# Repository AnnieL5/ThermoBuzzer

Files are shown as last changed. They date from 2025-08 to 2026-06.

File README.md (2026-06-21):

## ThermoBuzzer, a Thermosenser to Prevent Over Boiled Pots. 

### What it is
This device integrates a thermosensor, buzzer, and a button, and can make alarms when the temperature (the steam it detects) reaches a certain threshold. 

### Motivation / Inspiration / Problem

One Saturday afternoon my father left the stove, with the water heating up, for almost half an hour until the pot boiled dry and the fire alarm turned on, simply because he forgot the fact that the stove is still on. That moment inspired me to make a change - to build a device that could sense the temperature and alarm people that the burner is still active. 

### How to use it

1. Solder the electrical parts (see BOM) onto the PCB. Insert the PCB into the case and secure using m3 self-tapping screws

2. Insert the battery to start the machine. Slide in the lid and secure using a m3 self-tapping screw

3. Place it near the stoves. 

    Once the temperature continuously reaches 50 degrees (able to modify using a constant), ThermoBuzzer will beep continuously every five minutes until the button is clicked to ensure someone is there.

    Once the temperature reaches 70 degrees (able to modify using a constant), ThermoBuzzer will beep continuously right away until the button is clicked.

4. (Optional) To adjust the temperature threshold, take out the pcb from the case, modify amd reupload the program to the arduino pro mini.

### Code Example
Go checkout the example code in firmware/thermobuzzer.imo and upload it onto the arduino pro mini

For how to upload code onto arduino pro mini using arduino uno, check out 
https://www.instructables.com/How-to-Program-Arduino-Pro-Mini-Using-Arduino-UNO/

### Image of the entire cad / Finished product
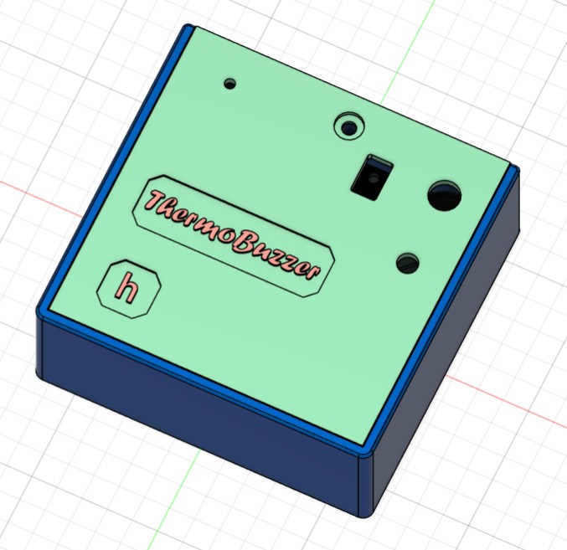
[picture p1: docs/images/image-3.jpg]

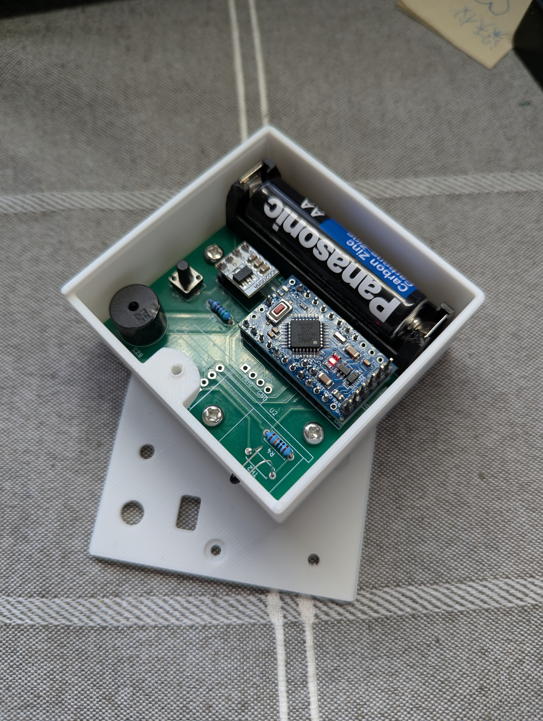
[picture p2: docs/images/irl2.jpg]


### Image of the entire cad (with lid) / Finished product
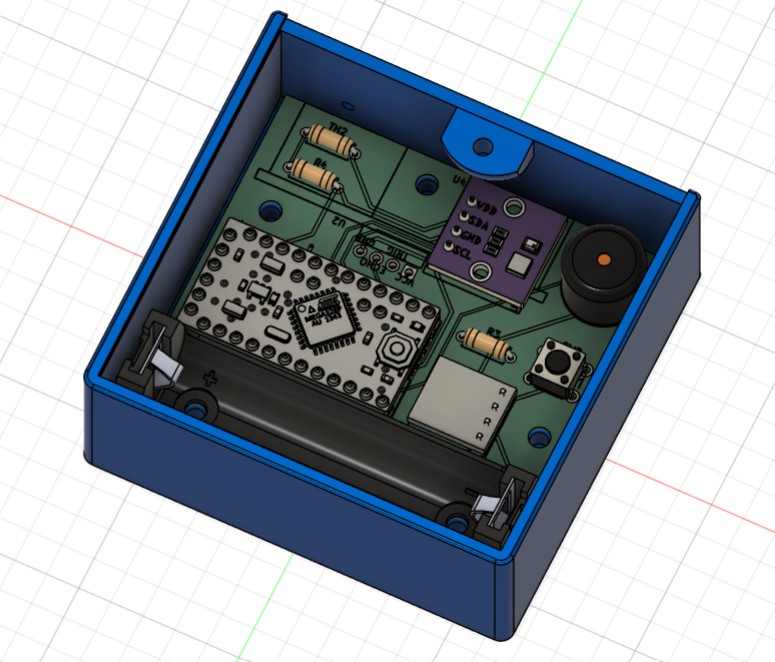
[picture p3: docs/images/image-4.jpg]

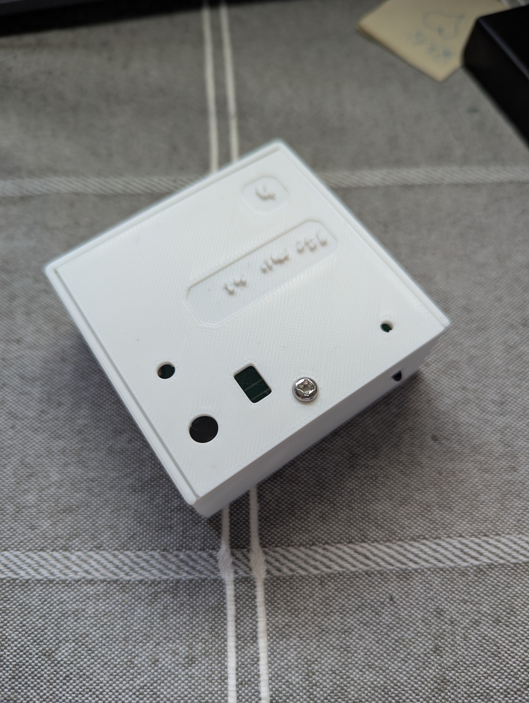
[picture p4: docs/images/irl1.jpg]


### Image of the final PCB
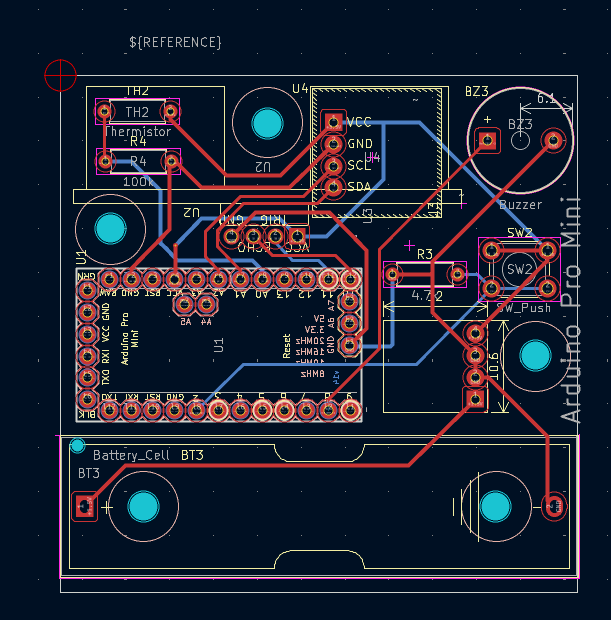
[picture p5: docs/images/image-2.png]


### Image of the wiring schematic
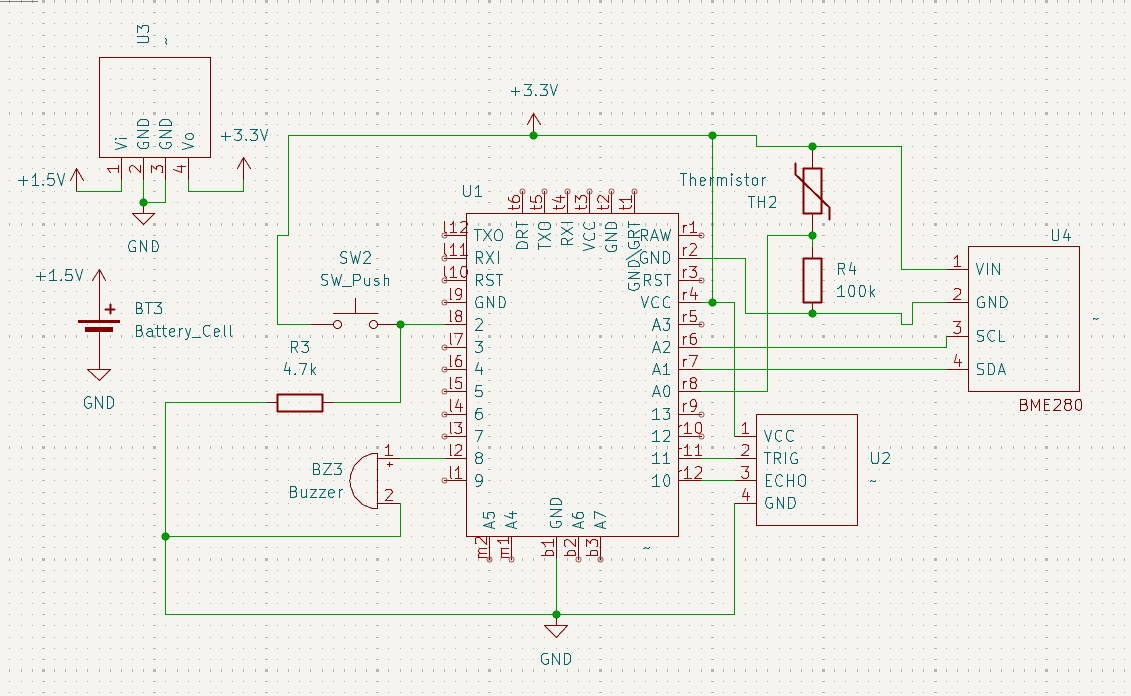
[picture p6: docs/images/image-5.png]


## Zine page

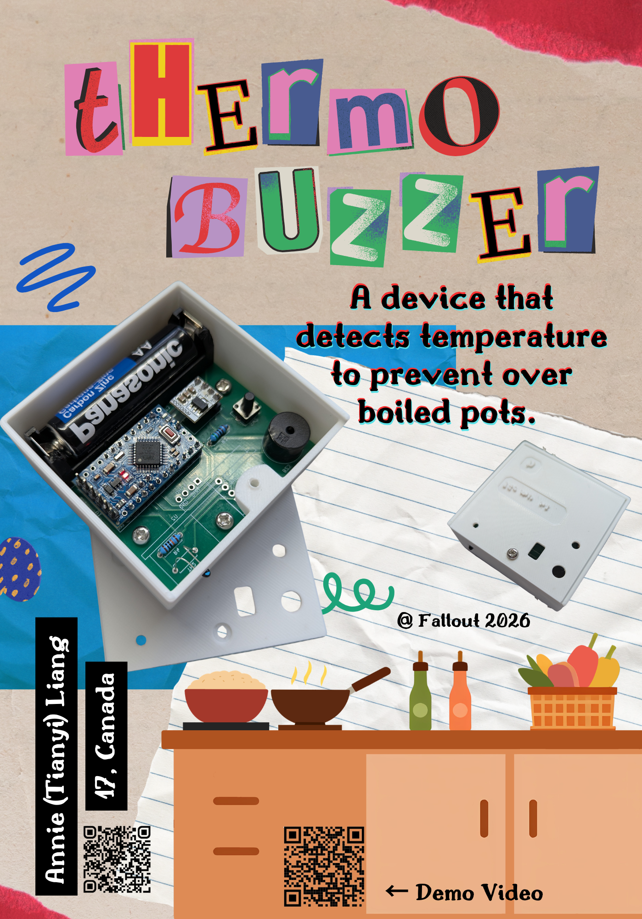
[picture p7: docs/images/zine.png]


## Demo Video

https://youtu.be/lv5Z6S4dAAs

## Product Design

### CAD dimensions
Side + top + base thickness: 2mm
supporting bar: r=4mm, h=4mm
Case height: 2mm base + 4mm supporting bar + 1.6mm board + 15.1mm battery height + 2mm flex + 2mm top

### Circuit Diagram 
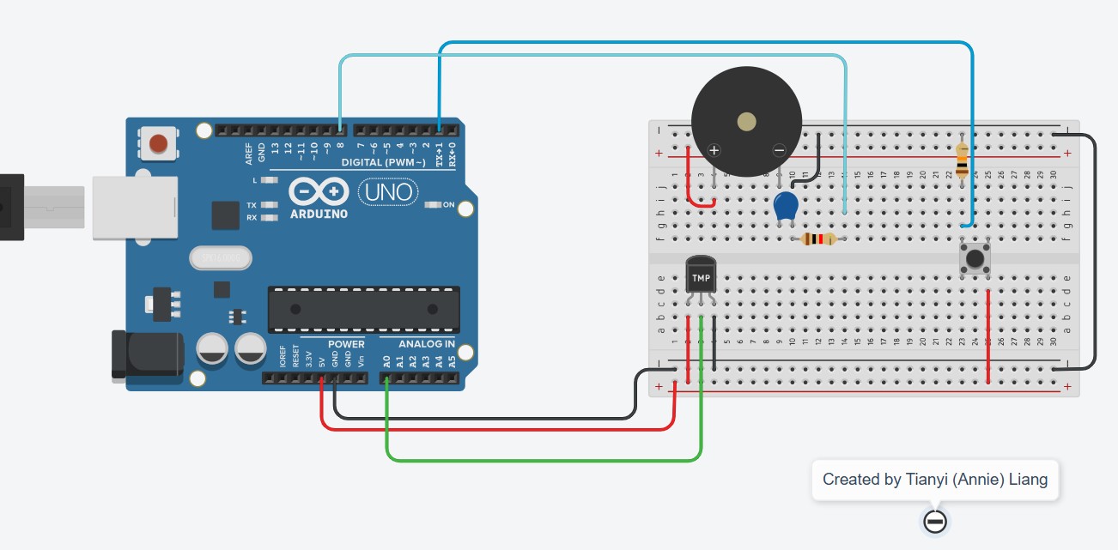
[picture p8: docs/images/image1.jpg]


### Sub-circuit Description
Diagrams from www.circuitbasics.com. 
#### Temperature sensor (NTC MF11) and Arduino

NTC MF11
The value of the resistor should be roughly equal to the resistance of the thermistor.
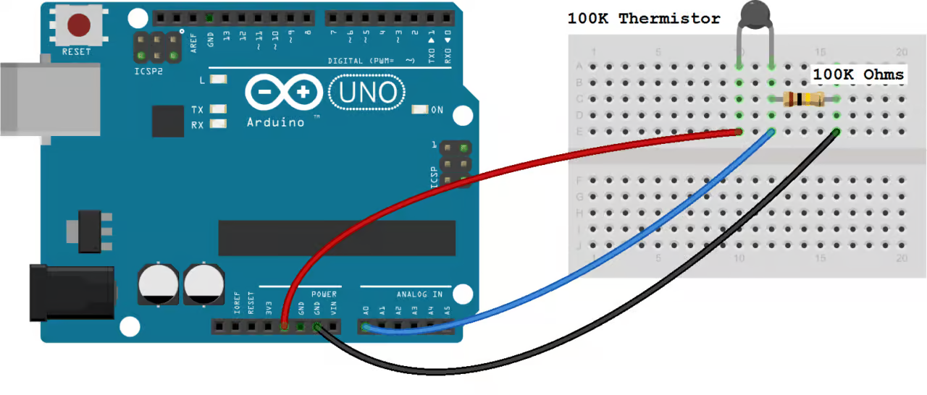
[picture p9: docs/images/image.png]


#### BME280
Reference links:

BME280
https://randomnerdtutorials.com/bme280-sensor-arduino-pressure-temperature-humidity/

https://docs.cirkitdesigner.com/component/3d8e6da8-841a-47a6-a1aa-0aa902c905e1/aht20bmp280

Code: https://randomnerdtutorials.com/bme280-sensor-arduino-pressure-temperature-humidity/

Arduino Library: adafruit bme280

It supports SPI or I2C communication

| BME280 |	Arduino |
|--|--|
|Vin | 	5V |
|GND |	GND |
|SCL |	A5 |
|SDA |	A4 |

| BME280 |	Arduino |
|--|--|
|SCK (SPI Clock)|	Pin 13|
|SDO (MISO)|	Pin 12|
|SDI (MOSI)|	Pin 11|
|CS (Chip Select)|	Pin 10|

#### Buzzer, Button and Arduino

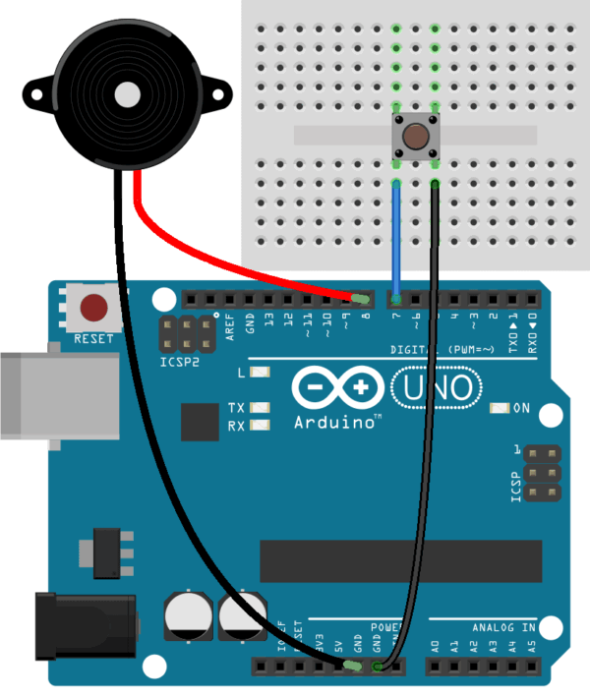
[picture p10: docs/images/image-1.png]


## Requirements (Need future work)
| Req # | Requirements |
|---|---|
| 1.1 | The thermosensor shall be able to measure the temperature accurately for further actions|
| 1.2 | The thermosensor shall be able to beep when the temperature reaches a certain threshold |
| 1.3 | The button should be able to stop the buzzer from beeping |
| 1.4 | The temperature threshold should be adjustable by the user |

## Bill of Materials (BOM)
| Product name | Product Description | Amount | Unit Price | Shipping Fee | Total Price | Link |
| --- | --- | --- | --- | --- | --- | --- |
| Arduino Pro Mini, | ÊATMEGA328P 3.3V 8MHz | 1 | $6.14 | | $6.14 | https://www.aliexpress.com/item/1005009384358010.html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 |
| Temperature Sensor, | AHT20+BMP280 | 1 | $4.59 | | $4.59 | https://www.aliexpress.com/item/1005005982427374.html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 |
| Thermisor, | 10PCS NTC ThermistorÊMF52 NTC-MF52AT | 1 | 3.46 | | $3.46 | https://www.aliexpress.com/item/1005007016386078.html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 |
| Passive Buzzer, | 10PCS Passive Buzzer Kits 12085 | 1 | 2.79 | | $2.79 | https://www.aliexpress.com/item/1005007038458518.html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 |
| Buttons, | 6\*6\*10mm 20pics | 1 | 2.29 | | $2.29 | https://www.aliexpress.com/item/1005006046180384.html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 |
| AA Battery, | 1 | NA | | | |
| THT Battery Holder | 14500 Battery Box With Pins 1AA 1.5V | 1 | 0.33 | 7.48 | $7.81 | https://www.aliexpress.com/item/1005005620966310.html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 |
| Voltage Regulator, | 0.8V-5V to 3V 3.3V 5V Boost Voltage Regulate | 1 | 3.85 | | $3.85 | https://www.aliexpress.com/item/1005006167931077.html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 |
| m3 self-tapping screw, | ZONSANTA M3x50pc 5mm | 1 | 2.79 | | $2.79 | https://www.aliexpress.com/item/4000982209705.html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 |
| resistor, | 100k | 1 | 0 | | $0.00 | |
| resistor, | 10k | 1 | 0 | | $0.00 | |
| head pins, | 5 male 5 female | 1 | 5.19 | | $5.19 | https://www.aliexpress.com/item/1005007235591794.html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 |
| Total | | | | | $38.91 | |

### Thanks for checking it out!
Any questions or thoughts, feel free to reach out to atianyi.liang@gmail.com.

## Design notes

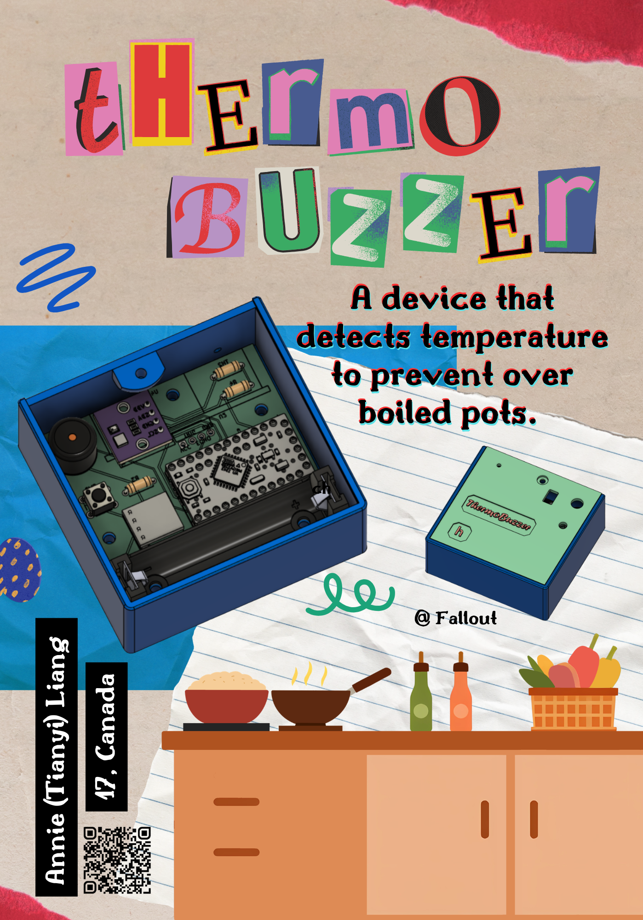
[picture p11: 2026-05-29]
docs/images/Thermobuzzer Zine Page PNG.png

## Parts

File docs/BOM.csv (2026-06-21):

Arduino Pro Mini | ÊATMEGA328P 3.3V 8MHz | 1 | $6.14 |  | $6.14 | https://www.aliexpress.com/item/1005009384358010.html?mp=1
Temperature Sensor | AHT20+BMP280 | 1 | $4.59 |  | $4.59 | https://www.aliexpress.com/item/1005005982427374.html?mp=1&sourceType=570
Thermisor | 10PCS NTC ThermistorÊMF52 NTC-MF52AT | 1 | 3.46 |  | $3.46 | https://www.aliexpress.com/item/1005007016386078.html?mp=1
Passive Buzzer | 10PCS Passive Buzzer Kits 12085 | 1 | 2.79 |  | $2.79 | https://www.aliexpress.com/item/1005007038458518.html?mp=1&sourceType=570
Buttons | 6*6*10mm 20pics | 1 | 2.29 |  | $2.29 | https://www.aliexpress.com/item/1005006046180384.html?mp=1
AA Battery |  | 1 | NA
THT Battery Holder | 14500 Battery Box With Pins 1AA 1.5V | 1 | 0.33 | 7.48 | $7.81 | https://www.aliexpress.com/item/1005005620966310.html?mp=1
Voltage Regulator | 0.8V-5V to 3V 3.3V 5V Boost Voltage Regulate | 1 | 3.85 |  | $3.85 | https://www.aliexpress.com/item/1005006167931077.html?mp=1
m3 self-tapping screw | ZONSANTA M3x50pc 5mm | 1 | 2.79 |  | $2.79 | https://www.aliexpress.com/item/4000982209705.html?curPageLogUid=Y5TAugc4ns7L
resistor | 100k | 1 | 0 |  | $0.00
resistor | 10k | 1 | 0 |  | $0.00
head pins | 5 male 5 female | 1 | 5.19 |  | $5.19 | https://www.aliexpress.com/item/1005007235591794.html?mp=1&sourceType=570
Total |  |  |  |  | $38.91

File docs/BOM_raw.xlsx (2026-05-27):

BOM
Part Name | Type | Reference Designator | Quantity | Price | Link | Price | Notes
Temperature Sensor | NTC MF11, AHT20+BMP280 |  | 1 | 2.19 | AHT20+BMP280 Temperature Humidity Air Pressure Module High-precision Digital Temperature Humidity and Air Pressure Sensor |  | https://www.aliexpress.com/ssr/300000512/BundleDeals2?productIds=1005007345095808:12000040354473755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 | https://www.amazon.ca/ANALOG-DEVICES-TMP36-Temperature-Sensor/dp/B00JYQAIBM
Active Buzzer | 5V |  | 1 | 3.99 | https://www.aliexpress.com/w/wholesale-active-buzzer.html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
Button |  |  | 1 | NA | https://www.aliexpress.com/w/wholesale-button-electronics.html?g=y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
Resistor
Capacitor |  |  | 1 |  | https://www.aliexpress.com/w/wholesale-capacitor.html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
Arduino | Arduino Nano (type) |  | 1 | $2.60 | https://www.aliexpress.com/item/1005004904865598.html?curPageLogUid=BISAlr5fLDLJ
 | Arduino pro mini |  |  | $6.19 | 1PCS Pro mini Atmega328 Pro Mini 328 Mini ATMEGA328P 3.3V 8MHz 5V 16Mhz for Arduino Compatible Nano CP2102 FT232RL
Battery | 9v dc |  |  | 9.98 | https://www.amazon.ca/Duracell-Coppertop-Long-lasting-All-Purpose-Household/dp/B0014D0SL8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
Battery socket
Boost voltage regulator |  |  |  | 3.3 | Mini 0.8V-5V to 3V 3.3V 5V Boost Voltage Regulate Board Low-Power-Consumption High-Efficiency DC-DC Step-up Converter Module
Product name | Product Description | Amount | Unit Price | Shipping Fee | Total Price | Link
Arduino Pro Mini | ATMEGA328P 3.3V 8MHz | 1 | $6.14 |  | $6.14 | https://www.aliexpress.com/item/1005009384358010.html?mp=1
Temperature Sensor | AHT20+BMP280 | 1 | $4.59 |  | $4.59 | https://www.aliexpress.com/item/1005005982427374.html?mp=1&sourceType=570
Thermisor | 10PCS NTC Thermistor MF52 NTC-MF52AT | 1 | 3.46 |  | $3.46 | https://www.aliexpress.com/item/1005007016386078.html?mp=1
Passive Buzzer | 10PCS Passive Buzzer Kits 12085 | 1 | 2.79 |  | $2.79 | https://www.aliexpress.com/item/1005007038458518.html?mp=1&sourceType=570
Buttons | 6*6*10mm 20pics | 1 | 2.29 |  | $2.29 | https://www.aliexpress.com/item/1005006046180384.html?mp=1
AA Battery |  | 1 | NA
THT Battery Holder | 14500 Battery Box With Pins 1AA 1.5V | 1 | 0.33 | 7.48 | $7.81 | https://www.aliexpress.com/item/1005005620966310.html?mp=1
Voltage Regulator | 0.8V-5V to 3V 3.3V 5V Boost Voltage Regulate | 1 | 3.85 |  | $3.85 | https://www.aliexpress.com/item/1005006167931077.html?mp=1
 |  |  |  |  | $0.00
 |  |  |  |  | $0.00
m3 self-tapping screw | ZONSANTA M3x50pc 5mm | 1 | 2.79 |  | $2.79 | https://www.aliexpress.com/item/4000982209705.html?curPageLogUid=Y5TAugc4ns7L
resistor | 100k | 1 | 0 |  | $0.00
resistor | 10k | 1 | 0 |  | $0.00
head pins | 5 male 5 female | 1 | 5.19 |  | $5.19 | https://www.aliexpress.com/item/1005007235591794.html?mp=1&sourceType=570
Total |  |  |  |  | $38.91
GarageGuarde
Ultrasonic sensor | HC-SR04 3.3-5VNew version | 1 | 2.71 |  | 2.71 | https://www.aliexpress.com/item/1005005467178145.html?curPageLogUid=PazbM33tgsR5
Passive Buzzer | 10PCS Passive Buzzer Kits 12085 | 1 | 0 |  | 0
Arduino Pro Mini | ATMEGA328P 3.3V 8MHz | 1 | $6.14 |  | $6.14 | https://www.aliexpress.com/item/1005009384358010.html?mp=1
AA Battery |  | 1 | NA
THT Battery Holder | 14500 Battery Box With Pins 1AA 1.5V | 1 | 0.33 | NA | $0.33 | https://www.aliexpress.com/item/1005005620966310.html?mp=1
Voltage Regulator | 0.8V-5V to 3V 3.3V 5V Boost Voltage Regulate | 1 | 3.85 |  | $3.85 | https://www.aliexpress.com/item/1005006167931077.html?mp=1
m3 self-tapping screw | ZONSANTA M3x50pc 5mm | 1 | 0 |  | $0.00 | https://www.aliexpress.com/item/4000982209705.html?curPageLogUid=Y5TAugc4ns7L
head pins | 5 male 5 female | 1 | 0 |  | $0.00 | https://www.aliexpress.com/item/1005007235591794.html?mp=1&sourceType=570
 |  |  |  |  | $51.94

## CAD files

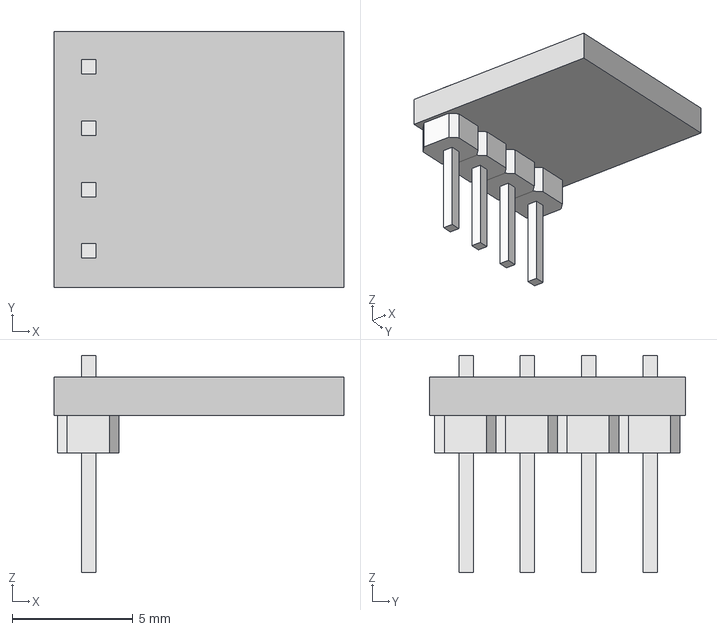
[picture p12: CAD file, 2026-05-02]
mechanical/Electric components/ND2050MA-3.step
12.0 x 10.6 x 9.00 mm

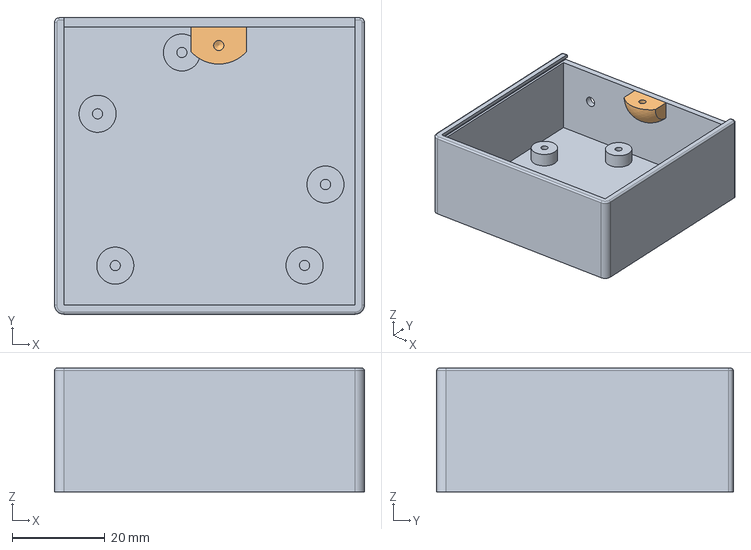
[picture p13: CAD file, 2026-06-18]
mechanical/thermobuzzer_case.step
66.9 x 64.0 x 26.7 mm

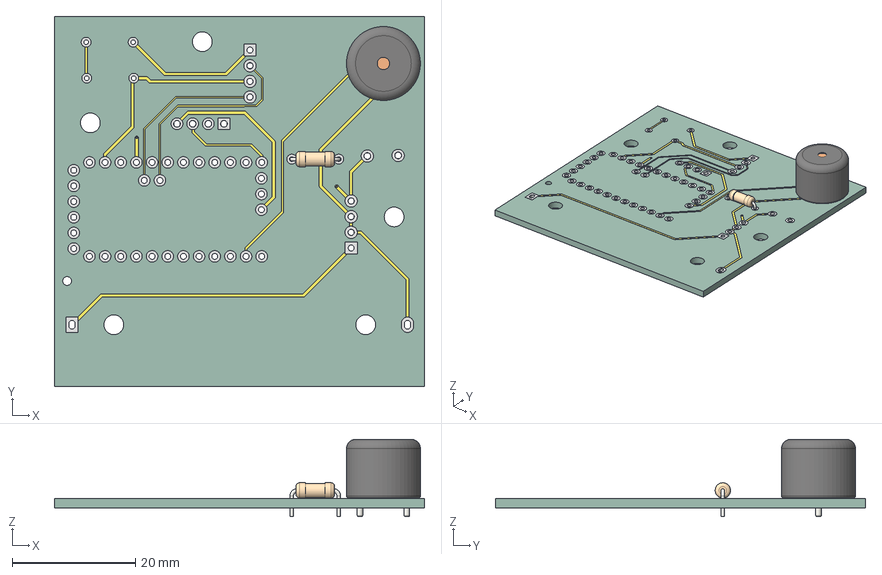
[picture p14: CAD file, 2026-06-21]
PCB/ThermoBuzzer_pcb/ThermoBuzzer_pcb3.step
60.0 x 60.0 x 12.5 mm
Buzzer_12x9.5RM7.6
R_Axial_DIN0207_L6.3mm_D2.5mm_P7.62mm_Horizontal
pcb_copper
pcb_pad
pcb_via
pcb_PCB

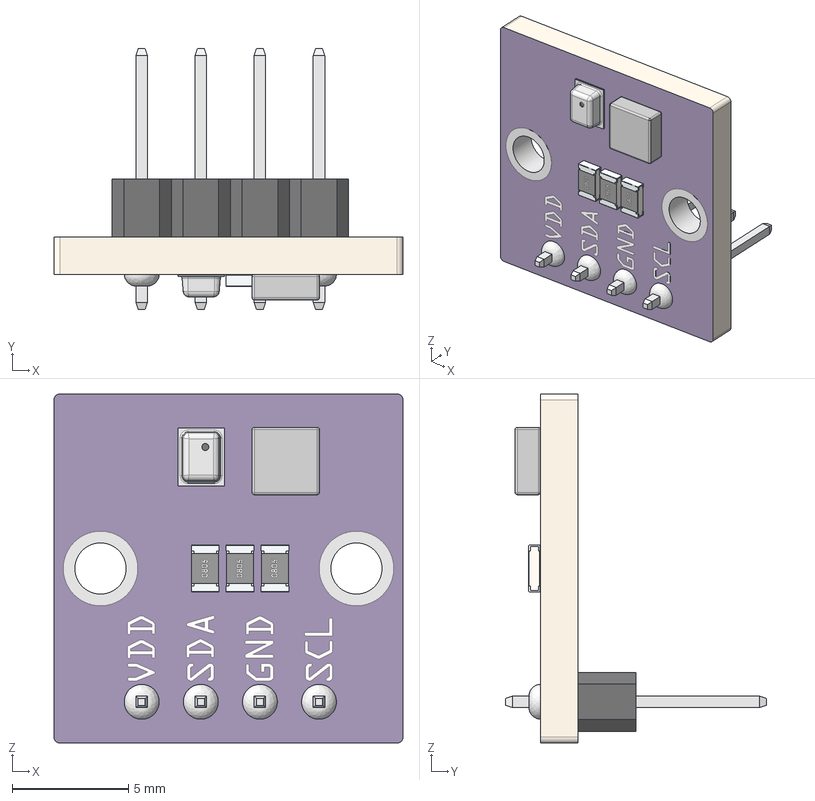
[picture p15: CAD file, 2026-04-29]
mechanical/Electric components/AHT20+BMP280.step
15.0 x 11.2 x 15.0 mm
Header Pins - Male x 4
SMD_0805 x 3
BMP280

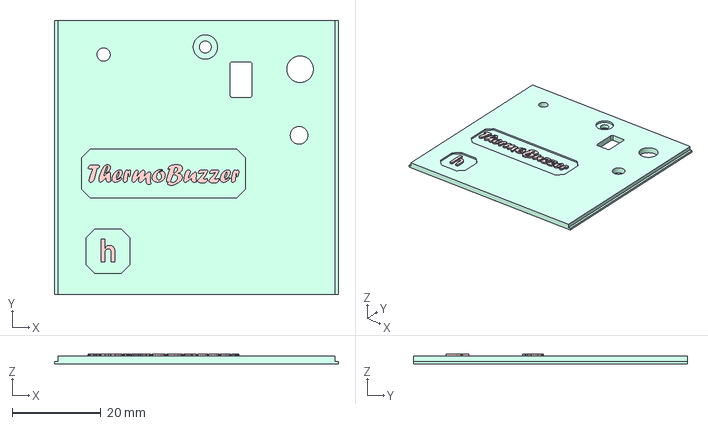
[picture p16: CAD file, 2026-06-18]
mechanical/thermobuzzer-lid.step
64.0 x 61.8 x 2.30 mm

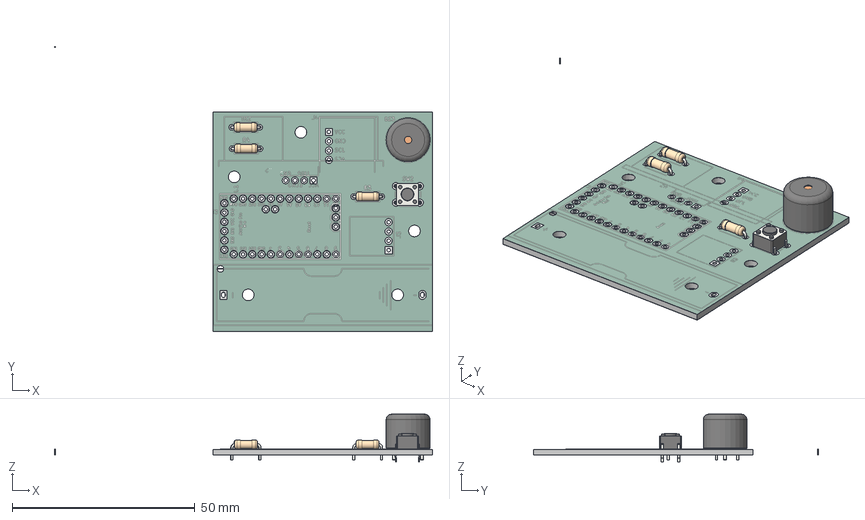
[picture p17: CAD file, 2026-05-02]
PCB/ThermoBuzzer_pcb/ThermoBuzzer_pcb.step
103.3 x 77.9 x 13.0 mm
Buzzer_12x9.5RM7.6
R_Axial_DIN0207_L6.3mm_D2.5mm_P7.62mm_Horizontal x 3
SW_PUSH_6mm
ThermoBuzzer_pcb_copper
ThermoBuzzer_pcb_pad
ThermoBuzzer_pcb_via
ThermoBuzzer_pcb_silkscreen x 2
ThermoBuzzer_pcb_soldermask x 2
ThermoBuzzer_pcb_PCB

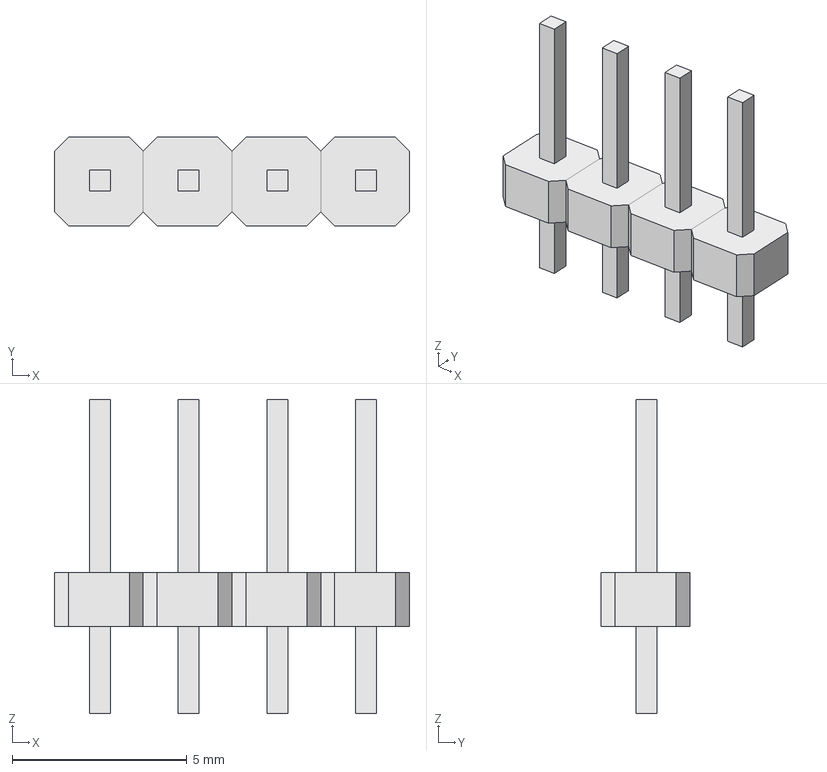
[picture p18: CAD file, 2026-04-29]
mechanical/Electric components/4PinHeader.step
10.2 x 2.54 x 9.00 mm

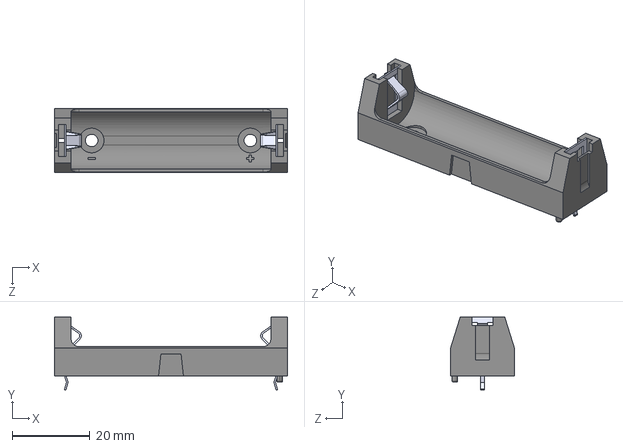
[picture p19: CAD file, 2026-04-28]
mechanical/Electric components/6S-AA Battery.STEP
60.0 x 18.7 x 16.5 mm

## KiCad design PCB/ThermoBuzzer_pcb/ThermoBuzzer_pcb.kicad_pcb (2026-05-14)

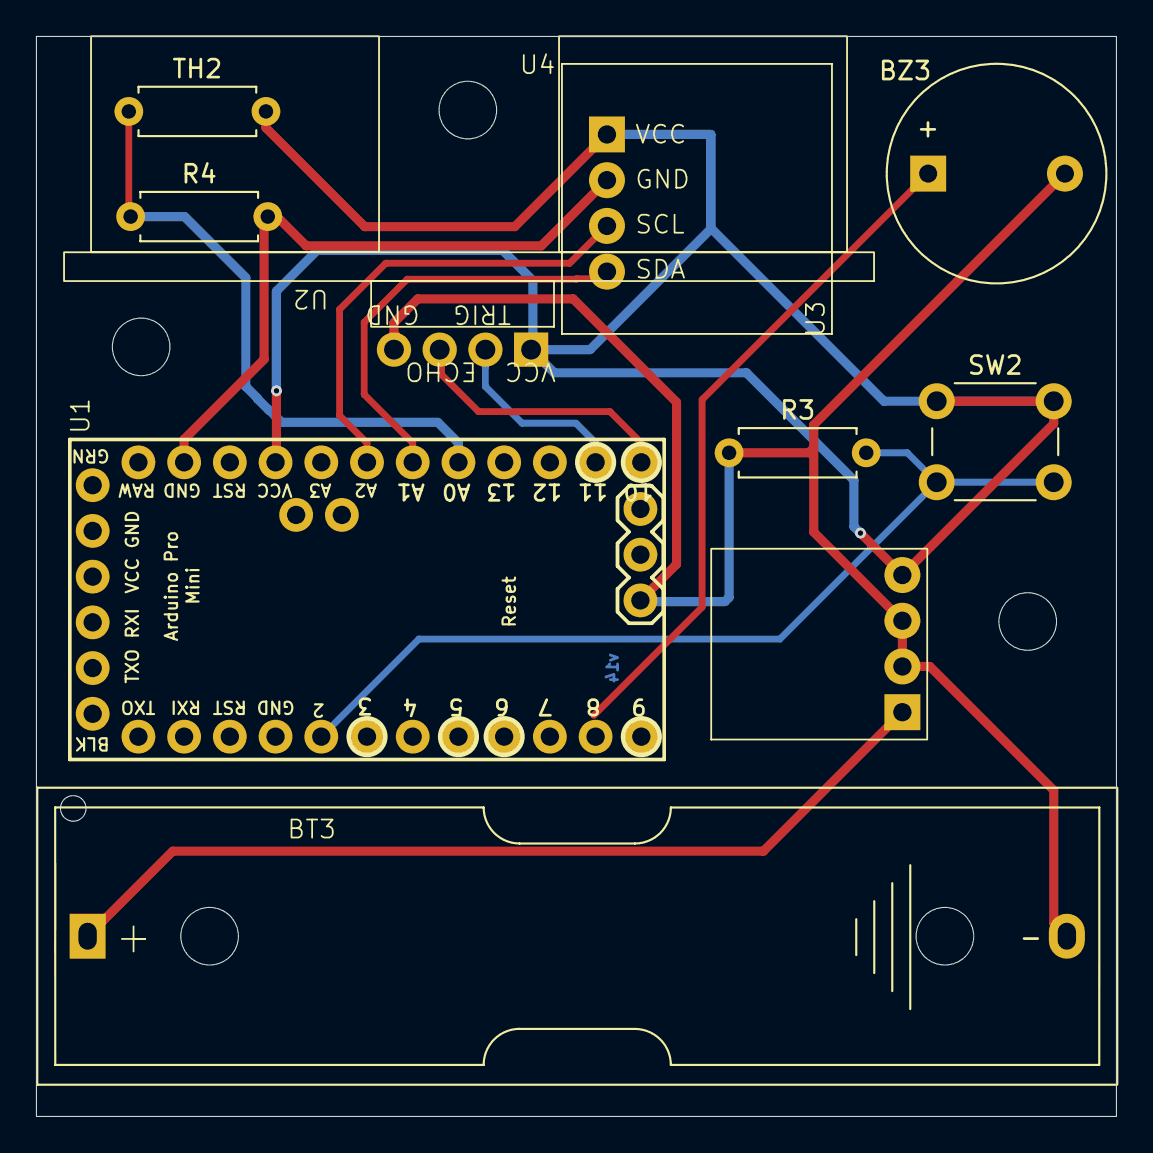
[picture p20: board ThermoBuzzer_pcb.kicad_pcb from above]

Board: 2 copper layers, 60.0 x 60.0 mm, 10 parts (0 on the bottom side), 11 nets.

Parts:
BT3: Battery_Cell; 6s-aa 14500
BZ3: Buzzer; Buzzer_12x9.5RM7.6
R3: 4.7k; R_Axial_DIN0207_L6.3mm_D2.5mm_P7.62mm_Horizontal
R4: 100k; R_Axial_DIN0207_L6.3mm_D2.5mm_P7.62mm_Horizontal
SW2: SW_Push; SW_PUSH_6mm
TH2: Thermistor; R_Axial_DIN0207_L6.3mm_D2.5mm_P7.62mm_Horizontal
U1: arduino_pro_mini_new
U2: Ultrasonic Sensor HC-SR04
U3: ND0205MA Voltage Regulator
U4: AHT20+BMP280

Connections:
+1.5V: BT3.1 (+), U3.1 (Vi)
+3.3V: SW2.1, TH2.2, U1.r4 (VCC), U2.1 (VCC), U3.4 (Vo), U4.1 (VIN)
GND: BT3.2 (-), BZ3.2 (-), R3.1, U1.b1 (GND), U2.4 (GND), U3.2 (GND), U3.3 (GND)
unnamed: BZ3.1 (+), U1.l2 (8)
unnamed: R3.2, SW2.2, U1.l8 (2)
unnamed: U1.r12 (10), U2.3 (ECHO)
unnamed: U1.r11 (11), U2.2 (TRIG)
unnamed: R4.1, TH2.1, U1.r8 (A0)
unnamed: U1.r7 (A1), U4.4 (SDA)
unnamed: U1.r6 (A2), U4.3 (SCL)
unnamed: R4.2, U1.r2 (GND), U4.2 (GND)

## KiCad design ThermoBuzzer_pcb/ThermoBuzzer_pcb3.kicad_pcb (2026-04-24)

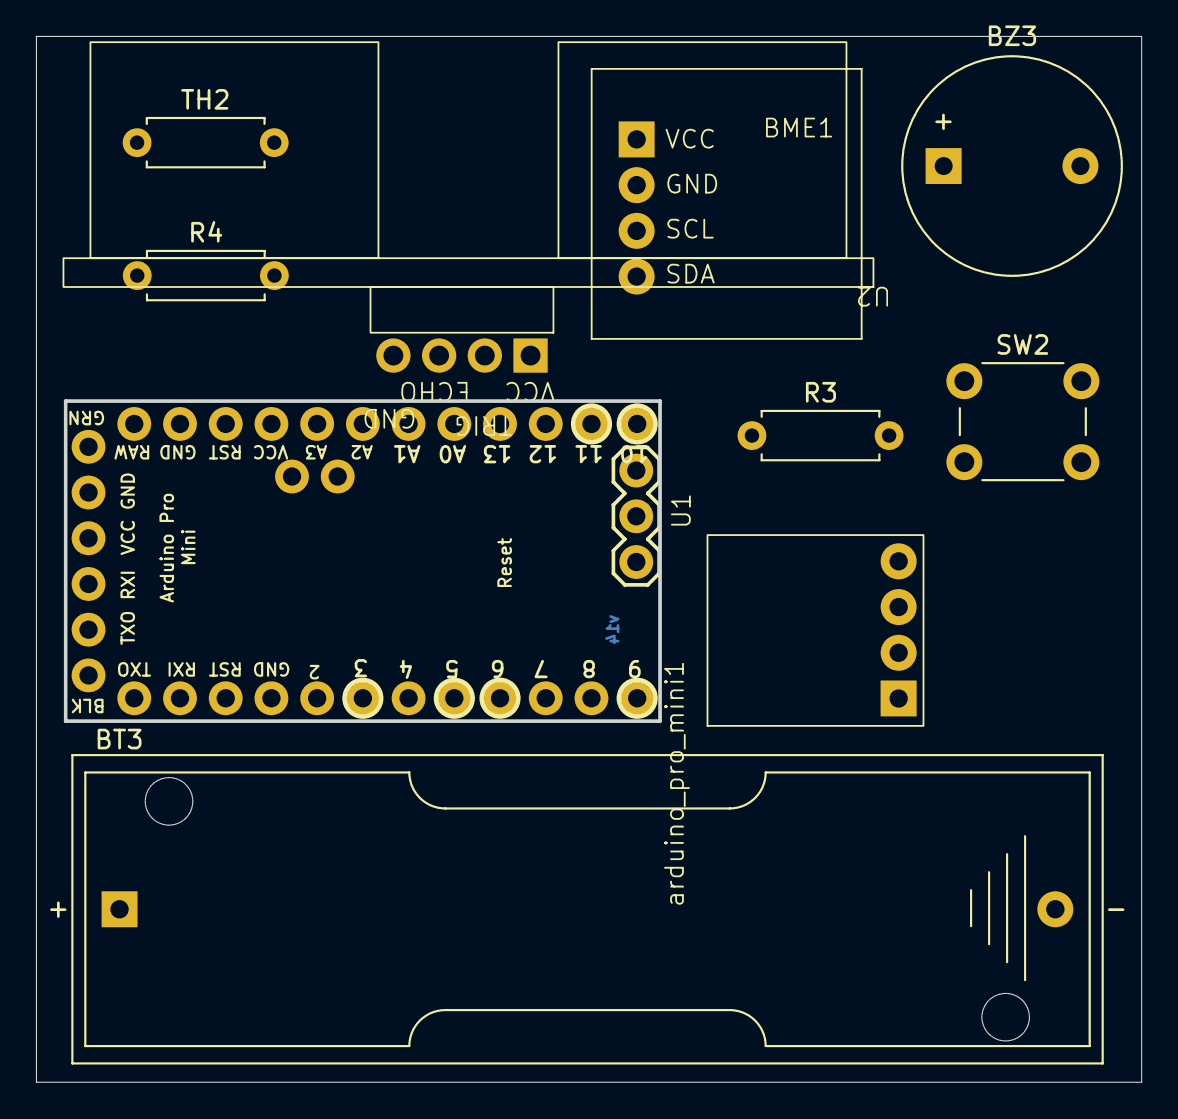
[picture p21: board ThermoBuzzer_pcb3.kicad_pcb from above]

Board: 2 copper layers, 61.4 x 58.1 mm, 10 parts (0 on the bottom side), 10 nets, no tracks yet.

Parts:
BME1: AHT20+BMP280
BT3: Battery_Cell; BatteryHolder_Keystone_2460_1xAA
BZ3: Buzzer; Buzzer_12x9.5RM7.6
R3: 100; R_Axial_DIN0207_L6.3mm_D2.5mm_P7.62mm_Horizontal
R4: 100k; R_Axial_DIN0207_L6.3mm_D2.5mm_P7.62mm_Horizontal
SW2: SW_Push; SW_PUSH_6mm
TH2: Thermistor; R_Axial_DIN0207_L6.3mm_D2.5mm_P7.62mm_Horizontal
U1: ND0205MA Voltage Regulator
U2: Ultrasonic Sensor HC-SR04
arduino_pro_mini1: arduino_pro_mini_new

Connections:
+1.5V: BT3.1 (+), U1.1 (Vi)
+3.3V: BME1.1 (VIN), SW2.1, TH2.1, U1.4 (Vo), U2.1 (VCC), arduino_pro_mini1.r4 (VCC)
GND: BME1.2 (GND), BT3.2 (-), BZ3.2 (-), R3.1, R4.2, U1.2 (GND), U1.3 (GND), U2.4 (GND), arduino_pro_mini1.b1 (GND)
unnamed: BME1.3 (SCL), arduino_pro_mini1.r6 (A2)
unnamed: BME1.4 (SDA), arduino_pro_mini1.r7 (A1)
unnamed: BZ3.1 (+), arduino_pro_mini1.l2 (8)
unnamed: U2.3 (ECHO), arduino_pro_mini1.r12 (10)
unnamed: U2.2 (TRIG), arduino_pro_mini1.r11 (11)
unnamed: R3.2, SW2.2, arduino_pro_mini1.l8 (2)
unnamed: R4.1, TH2.2, arduino_pro_mini1.r8 (A0)

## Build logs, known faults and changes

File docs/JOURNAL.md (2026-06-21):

# ANNIE'S Journal

__Note: all parts will be funded my self, and all koi earned from this project will be spent towards travel grant or other items in the shop__

## Mar. 21

Todo:
 - [ x ] Finish Research Electronics
    - Might not need the capacitor?
 - [ x ] Complete Schematics
    - need to finalize what part to buy -> version
    - Finalize battery

 - Added product design section of README

Tomorrow:
 - [ ] Select electronics - finish BOM
 - [ ] Finalize Schematics
 - [ ] Work on PCB

## 3.23

1. Continue working on parts

For temperature sensor:
- The AHT20 is a budget-friendly humidity/temp sensor
- BME280 adds pressure for a comprehensive, but sometimes self-heating, environmental package. 
- AHT20+BME280/BMP280 combined module leverages the best of both: AHT20's improved humidity accuracy and the Bosch chip’s precision pressure/temp sensing

2. Finalized parts for Arduino and temperature sensor

Tomorrow:
- Verify if the buzzer needs a capacitor

## April 4
Completed
- Buzzer does not need a capacitor
- Changed schematics a bit - compile a sketch that includes both thermosensors
- Started and almost done with footprints
Tomorrow:
- Hopefully finish footprints and work on pcb tomorrow!!

## 4.5
- [x] Researched more in terms of powering the system
   - Switch from arduino nano to arduino pro mini
      - able to power with 3.3v - same as thermosensor
      - power with a AA battery & a step up converter
      
Tomorrow:
- research scale up converter + buzzer

## 4.6
- [ ]Finalize design:
   - arduino pro mini + BME280 + AA battery + power booster

## 4.15
- [ ] continue work on schematics + footprint
   - Update + complete the schematics

Challenge: 
- Could not figure out the footprint for arduino pro mini
   - found one online but couldn't figure out how to import it into the project
   - Tmr: try just copy pasting it in

## 4.16
Completed:
- Three more footprints assigned!!
- Created my first every custom footprint
Learned:
- How to make a Kicad footprint
   1. Create a rectangle
   - Press Alt + 3 to preview
   - To create a custom footprint: search up the datasheet for a part
Challenge:
- Can not find the dimension for the Arduino pro mini
Tomorrow:
- Arduino pro mini!!

## 4.17
Completed:
- Almost done with arduino pro mini footprints!!
Struggle:
- could not past the schematic
Solved with:
- Create the footprint on with the pcb file. Modify later

## 4.18
Completed:
- Finish arduino pro mini footprint
- Finish assigning pin numbers to all -> no error when importing schematic to PCB
- Imported all parts to PCB and arranged them slightly
Struggle:
- Found a footprint for Battery holder 1xAA
   - potentially switch to a pcb battery holder - searching for it on aliexpress 

Potentially I can combine the pcb for this with the Garage door detector (my future project) -> cheaper to manufacture

## 4.20
Completed:
- Added schematic + footprint for battery + voltage regulator

Challenge:
- had to calculate the operating voltage required - if 1xAA battery works
- need to calculate resistor type for the thermometer
   - potentially switch to LM35?

## 4.21

Todo:
- Wire everything
Challenge:
- Optimize everything so it fits on a small board
   - Tried different layouts
   - Be creative!!

## 4.22

Completed
- Revised some footprints
   - made the hole diameter bigger for some
   - Revised footprint layout for the thermosensor
Tomorrow: 
- Wire PCB!

## 4.23
Completed:
- Wire pcb
Challenge:
- Couldn't match up everything
   - change mil grid
   - Rewire everything tomorrow

## 4.24
Completed
- Rewired everything
   - Had to use thicker wires (20 mil) for VCC and GND, and thinner ones (15mil) for other connections
Challenge  
- Couldn't connect two pins
   Figured out after a lot of trying and rerouting.

## 4.25
Completed
- mark pcb dimensions
- basic cad sketch

## 4.26

Completed
- Revised the footprint for the battery
   - Challenge: find the dimension
   - Solved: found a cad 3d model online -> export to Fusion360 and get dimensions from that
- Continue working on 3d print
   - Decided to add holes on the PCB and use 3m self-tapping screws for securing it on in the box

## 4.27
Completed
- revised BOM
   - added specific columns, including part name, description, unit price, amount, and total price
- Had to compare and contrast to minimize shipping fee

## 4.28
Completed
- Continued working on the BOM
   - Make sure everything add up to the Aliexpress cart
- Revised schematics
   - Thermobuzzer now will use two resistors: 100k that works with the 100k thermistor, and 4.7k with button
   - Modified position of parts to ensure the screws can be correctly located and not interfere with cu.back
Challenge:
- Manage to arrange parts, wire, and the hole to fit in a small space

## 4.29
Completed
- Manage to create a cad of pcb + components
   - included preexisting cad from the internet for some components
   - also made my own
Challenge:
- Ran out of edible documents in Fusion 360 :(
- Tried to work around by deleting electronics I have imported assuming it will stay in the assembly
- NOO THEY DID NOT TvT Most components got deleted and the positions are not saved when re-imported [cry][cry]

## 4.30

Completed
- revised the sketch for the box
- created the box
- created the slide open lid by following a tutorial
   - Learned: to be honest, everything in that video are pretty useful

## 5.1
Completed:
- Make the lid of the box
- Connect all the STEP file of electronics to the footprints
Challenge:
- the updated 3d model of the electronics does not show up
Fix:
- update the electronics
   - also double check the wires!

** Also brought the parts!
Decided to buy the parts myself and use the koi from this project for travel and hotel grant

Tomorrow: 
- add the pcb cad to the case cad

## 5.3

Completed:
- Inserted the cad of the pcb into the case design

Challenge:
- Realized that the height of the case is 21.3 instead of 26.7 -> could not fit the pcb

Learned:
- Modify the parameter using the **timeline** tool

## 5.4

Completed:
- Revised the github readme page
   - added how to use section
   - verified that everything is added

- Created and completed the zine page

## 5.5

Completed
- Revised cad design 
   - made the button holes smaller
   - added another hole on the side wall in case the thermistor can not reach the the whole on top
- Organized the files

## 5.6

Completed:
- Revised file structure
   - created master folder: docs, firmware, mechanical
- Revised Readme
   - added more guide
   - more polished

## 5.7
- Revised path for pcb 3d model

## 5.11
- Export CAD files for separate parts
- revised pcb based on the new file structure and pcb design

## 5.13

- Polish CAD
   - update pile location
   - update connection location
   - update lid extrudsion 

Learned:
- I couldn't move the sketch for the connection previously -> just remove the constrain

## 5.26

Polished & Everything learned:
- Rounded corners using Fillet
- Added text onto the design using sketch -> text function
- changed colors using A (appearance)

## 5.28

Completed:
- Further polished CAD
- Rounded the corners even more
- Added Counterbore to the lid's hole

Challenge:
- Counterbore hole would not show
Fix:
- Change Apply to Object (at the really end of the panel) -> select the one for all objects

# Design Approved!

## 6.17
Parts + PCB arrived:
- Tested each component individually
   - program arduino pro mini using arduino uno\
   Mini's Vcc = UNO's +5v/3.3v (depends on the board you have)
   Mini's GND = UNO's GND.
   Mini's Tx = UNO's TX (pin no. 1)
   Mini's Rx = UNO's RX (pin no. 0)
   Mini's DTR = UNO's RESET.
   Mini onboard LED = Pin 13
   - Tested thermistor - working
   - Tested button - all good
   - Tested voltage booster - working

Challenge:
- Buzzer: since the aliexpress page does not contain the dimension and user manual, I created the footprint using the ones online -> apparently they are not the same

   Fix: Do not buy parts ever again that does not have a user manual. Look for more options I'm sure there's one

- I also couldn't differentiate passive vs active buzzer.

   Fix: Passive: both pins are the same length, no sticker on top.\
   Active: one pin longer than the other one, a sticker on top. 

   Passive: tone(). \
   Active: pin(high)\pin(low)

- Couldn't find 4.7k resistor

   Fix: since it is just pull down, I used 5k1 instead

- Battery holder does not fit into the pcb

   Fix: I should probably make the holes bigger just in case

- The screws's diameter decreases downwards and the hole in the CAD case is probably too big to hold it

   Fix: I made the ones on bottom 2.7mm -> 2.2mm diameter.

Would be great to double check everything just in case!

- Also started soldering everything in

   Challenge: did something wrong and had to get it out

   Next time: double check everything before soldering! 

## 6.20

Completed:
- Built the project
- Tested everything & it works!
- Refined the 3d print
- Filed videos + took pictures
- Created a demo video + posted on Youtube!

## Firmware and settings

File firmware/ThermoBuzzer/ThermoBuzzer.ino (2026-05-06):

const int BUZZERPIN = 8;
const int TEMPPIN = A0;
const int buttonPin = 2;  // the number of the pushbutton pin

const int TEMP_ADJUST = -2; //Seems that sensor is always showing about 2 deg too high
long currentMillis=0;
long previousMillis=0; //make sure that we check temperature right at the beginning
long currentMillis2=0;
long timerStartT=0; 
long tDronpt
int tempReading; //raw ADC temp reading from 0 to 1023
double tempK; //calculated temperature in degrees Kelvin

int buttonPressed;
bool overTemp = false;

// the setup function runs once when you press reset or power the board
void setup() {
  // initialize digital pin LED_BUILTIN as an output.
  pinMode(BUZZERPIN, OUTPUT);
  pinMode(TEMPPIN, INPUT);
  pinMode(buttonPin, INPUT);
}

void updateTemp()
{
  
  currentMillis=millis();
  if ((currentMillis-previousMillis)>=1000) //Update every 5 seconds
  {
    float tempC=readTemperature(); //read temp
    if(tempC > 28)
    {
      // buzz();
      if(!overTemp){
        overTemp = true;
        timerStartT = millis();
      }
      currentMillis2 = millis();
      if ((currentMillis2-timerStartT)>=2000) //Update every 10 seconds
      {
        // buzz();
        buttonPressed = digitalRead(buttonPin);
        while (buttonPressed == LOW){
          buzz();
          buttonPressed = digitalRead(buttonPin);
        }
        timerStartT = millis();
      }
    }else{

    }
    previousMillis = millis();
  }
  
}

float readTemperature()
{
tempReading = analogRead(TEMPPIN); //Raw reading from 0 to 1023
tempK = log(10000.0 * ((1024.0 / tempReading - 1))); //See datasheet for formula
tempK = 1 / (0.001129148 + (0.000234125 + (0.0000000876741 * tempK * tempK )) * tempK ); // Temp Kelvin
float celsius = tempK - 273.15 + TEMP_ADJUST; // Convert Kelvin to Celsius plus a TEMP_ADJUST
return celsius;
}

void buzz()
{
  digitalWrite(BUZZERPIN, HIGH);  // turn the LED on (HIGH is the voltage level)
  delay(1000);                      // wait for a second
  digitalWrite(BUZZERPIN, LOW);   // turn the LED off by making the voltage LOW
  delay(1000); 
}

// the loop function runs over and over again forever
void loop() {
  updateTemp();                     // wait for a second
}

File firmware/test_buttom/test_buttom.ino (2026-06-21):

const int buttonPin = 2;  // the number of the pushbutton pin


int buttonPressed;

// the setup function runs once when you press reset or power the board
void setup() {
  // initialize digital pin LED_BUILTIN as an output.
  pinMode(buttonPin, INPUT);
  pinMode(13, OUTPUT);
}





// the loop function runs over and over again forever
void loop() {
  // digitalWrite(13, HIGH); 
  buttonPressed = digitalRead(buttonPin);
  if (buttonPressed == LOW){
    digitalWrite(13, HIGH);   // Turn the LED on
    // delay(500);              // Wait for a second
    }    
  digitalWrite(13, LOW);    // Turn the LED off
  // delay(500);                 // wait for a second
}

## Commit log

2025-08-26 Add circuit diagram
2026-03-21 Update readme, create BOM and started PCB
    [BOM.xlsx, ThermoBuzzer_pcb.kicad_pcb, ThermoBuzzer_pcb.kicad_sch]
2026-03-22 Further work on Schematics + parts
    [BOM.xlsx, ThermoBuzzer_pcb.kicad_sch]
2026-03-24 Finalize arduino + temperature
    [BOM.xlsx, ThermoBuzzer_pcb.kicad_sch]
2026-04-05 april 4 schematic + footprints
    [BOM.xlsx, ThermoBuzzer_v2_pcb.kicad_sch]
2026-04-06 april 5 update
    [BOM.xlsx]
2026-05-14 create pcb folder
    [Arduino-Promini-footprint.kicad_pcb, ThermoBuzzer_pcb.kicad_pcb, ThermoBuzzer_pcb.kicad_sch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]
2026-05-29 organize folders
    [Arduino-Promini-footprint.kicad_pcb, ThermoBuzzer_pcb2.kicad_pcb, ThermoBuzzer_pcb3.kicad_pcb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]
2026-06-21 update bom
2026-06-21 maybe this will work?
    [BOM.csv]
2026-06-21 maybe this?
    [BOM.csv]
